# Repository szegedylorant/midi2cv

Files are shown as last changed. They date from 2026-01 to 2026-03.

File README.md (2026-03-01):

# MIDI Interface

MIDI to Clock, CV and Gate interface in 4 hp wide Eurorack format based on the Arduino Nano v3.

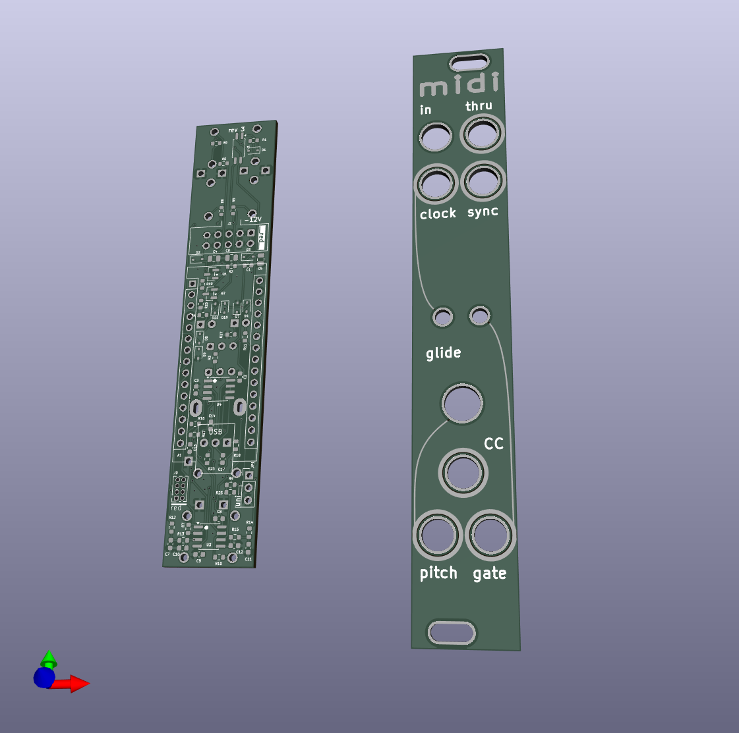
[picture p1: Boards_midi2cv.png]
Boards Image
 "3d rendered image of the two boards"

## Functions

* 4hp wide
* TRS MIDI Type A
* Hardware MIDI Thru
* MIDI clock to 16th note clock signal
* MIDI clock to DIN SYNC 24ppqn signal
* MIDI CC using 7 bit PWM Output
* 1V / Octave Pitch CV using 7 bit PWM Output
* Note glide knob
* Note on gate output

## Sources

### Code based on:
* - https://github.com/dhaillant/midi8d
* - https://github.com/kassu/KassutronicsQuantizer
 
### Hardware based on:
* - https://n-audio.net/designing-midi-in-and-midi-out-schematics/
* - https://github.com/dhaillant/midi8d
* - https://github.com/kassu/kassutronics/tree/master/documentation/Quantizer

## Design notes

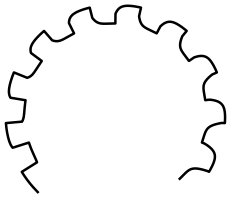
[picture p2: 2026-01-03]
hardware/square_to_lowpass_arc_270deg_CW_RCx1p5_tight.png

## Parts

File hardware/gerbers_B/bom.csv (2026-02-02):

Comment | Designator | Footprint | LCSC
4k7 | R24,R27 | Resistor_SMD:R_0603_1608Metric | C23162
1N5819WS | D2,D3,D4,D7,D8,D9,D10,D11 | Diode_SMD:D_SOD-323 | C191023
1k | R2,R7,R8,R9,R10,R11,R19,R20,R23 | Resistor_SMD:R_0603_1608Metric | C21190
10u | C4,C5,C6 | Capacitor_SMD:C_0805_2012Metric | C15850
100n | C1,C2,C3,C8,C9 | Capacitor_SMD:C_0603_1608Metric | C14663
TL072 | U3,U4 | Package_SO:SOIC-8_3.9x4.9mm_P1.27mm | C6961
10n | C17 | Capacitor_SMD:C_0603_1608Metric | C57112
15k | R12,R13,R14,R15,R16,R17 | Resistor_SMD:R_0603_1608Metric | C22809
1n | C7,C10,C11,C12,C13,C14 | Capacitor_SMD:C_0603_1608Metric | C1588
100k | R4,R25 | Resistor_SMD:R_0603_1608Metric | C25803
100 | R18 | Resistor_SMD:R_0603_1608Metric | C22775
1M | R3 | Resistor_SMD:R_0603_1608Metric | C22935
220R | R1,R5,R6 | Resistor_SMD:R_0603_1608Metric | C22962
MMBT5551L | Q1,Q2 | Package_TO_SOT_SMD:SOT-23 | C2145
1N4148WS | D1 | Diode_SMD:D_SOD-323 | C2128
EL3H7(C)(TA)-G | U1 | Package_SO:SSOP-4_4.4x2.6mm_P1.27mm | C92243

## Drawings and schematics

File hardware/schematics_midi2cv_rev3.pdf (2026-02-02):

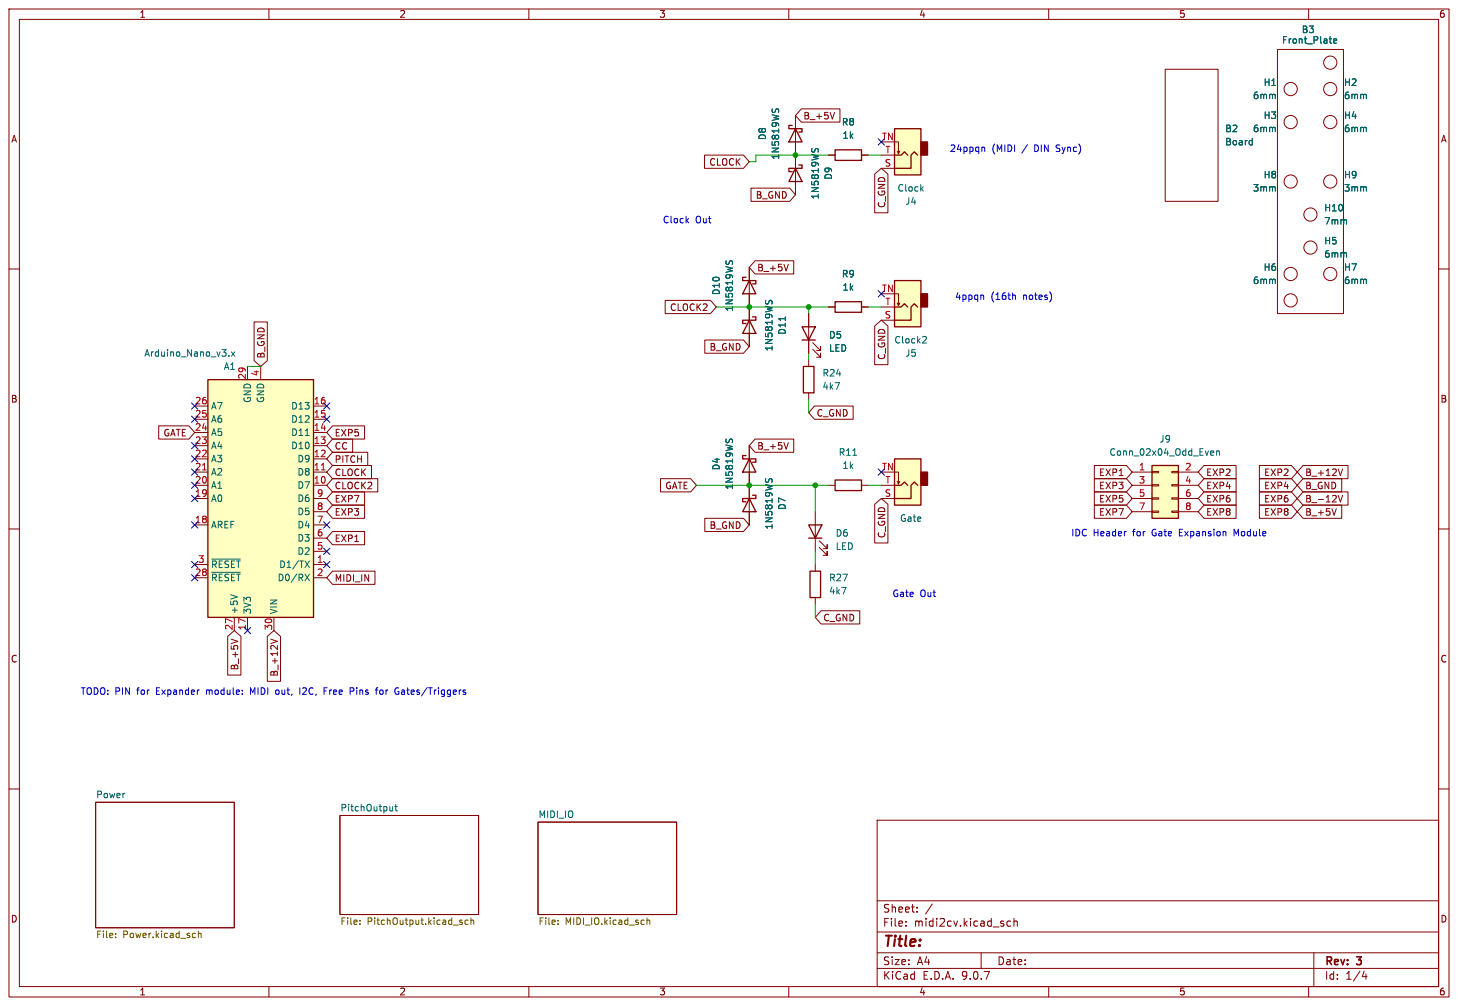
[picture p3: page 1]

Id: 1/4 Title: File: midi2cv.kicad_sch Sheet: / MIDI_IO

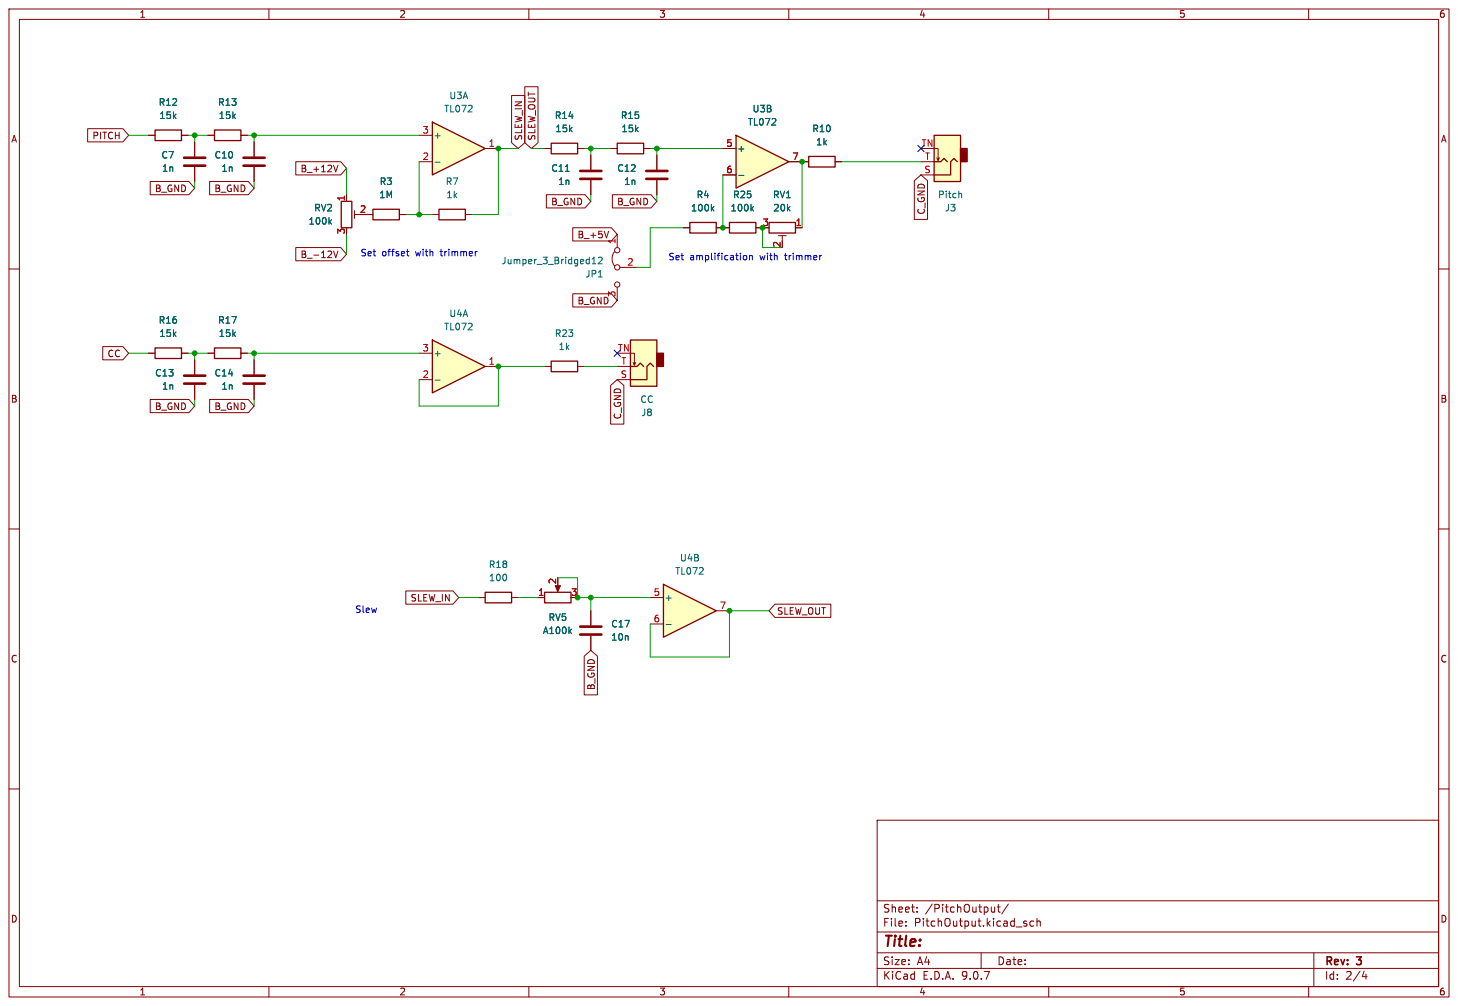
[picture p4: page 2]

Id: 2/4 Title: File: PitchOutput.kicad_sch Sheet: /PitchOutput/

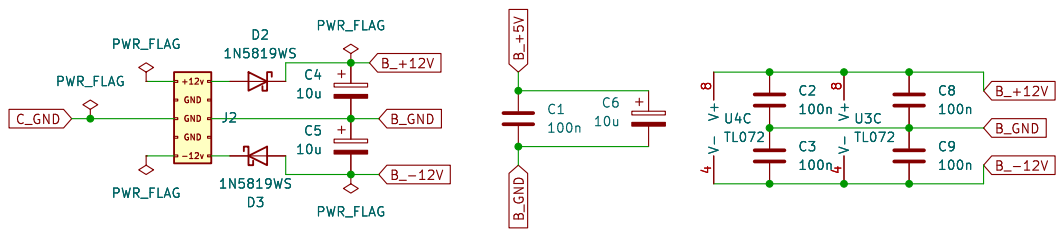
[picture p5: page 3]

Id: 3/4 Title: File: Power.kicad_sch Sheet: /Power/

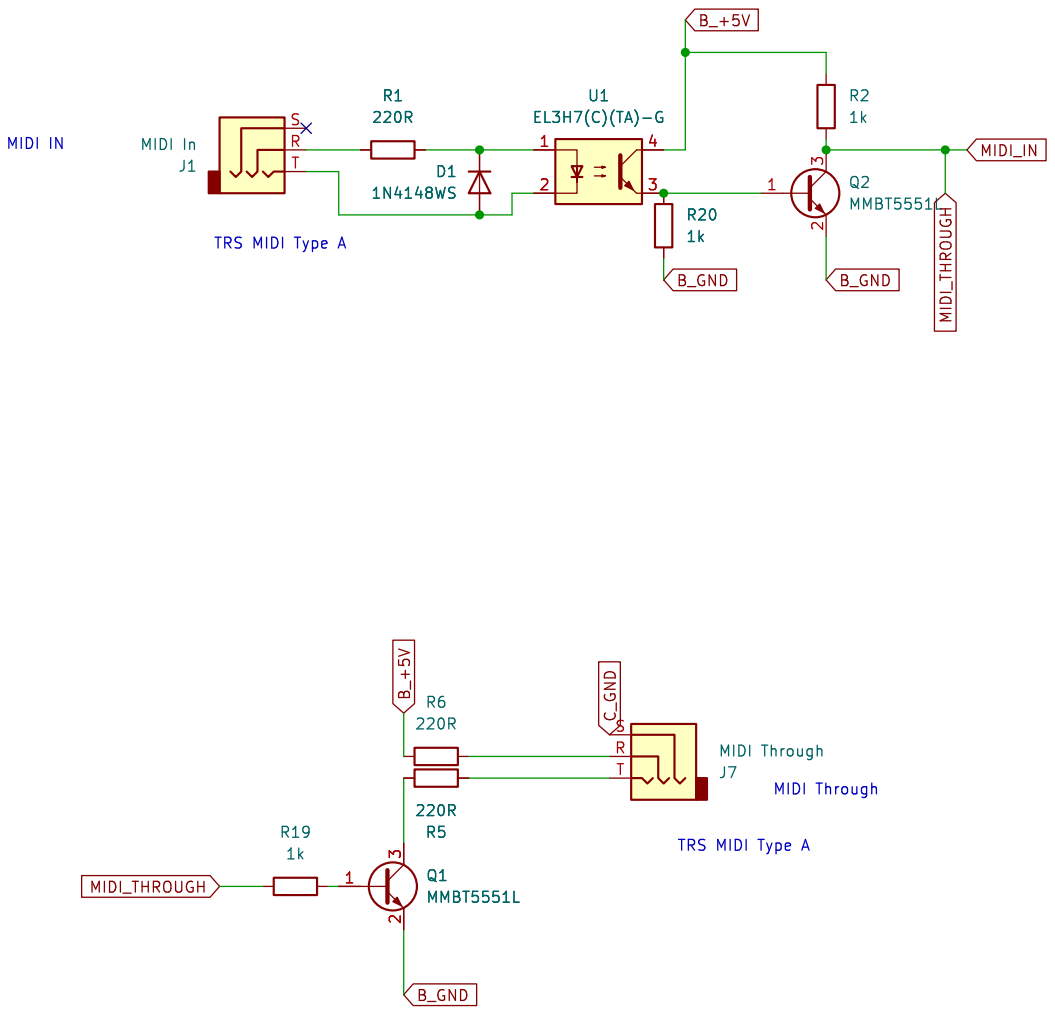
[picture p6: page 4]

TRS MIDI Type A MIDI Through Q1 MMBT5551L

Id: 4/4 Title: File: MIDI_IO.kicad_sch Sheet: /MIDI_IO/

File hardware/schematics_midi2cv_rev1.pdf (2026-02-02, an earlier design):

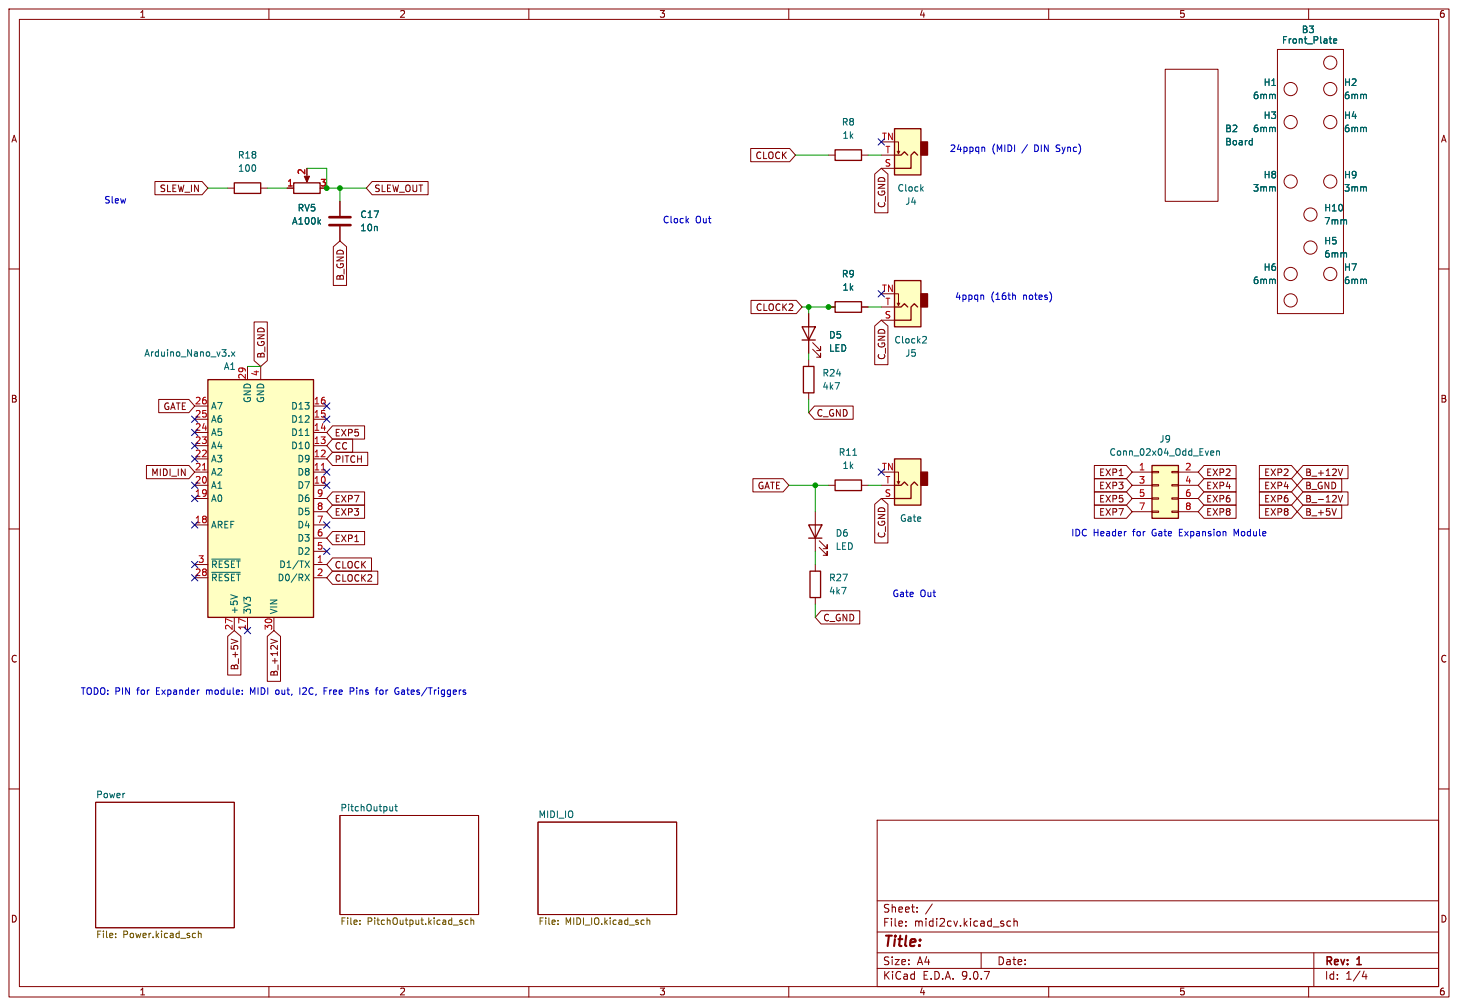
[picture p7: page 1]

24ppqn (MIDI / DIN Sync) Clock Out

IDC Header for Gate Expansion Module TODO: PIN for Expander module: MIDI out, I2C, Free Pins for Gates/Triggers

Id: 1/4 Title: File: midi2cv.kicad_sch Sheet: / MIDI_IO

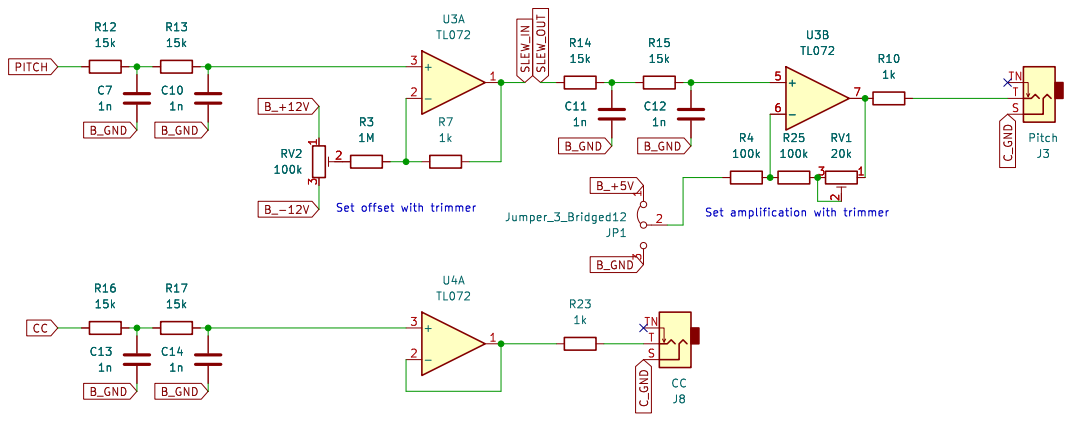
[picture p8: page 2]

Id: 2/4 Title: File: PitchOutput.kicad_sch Sheet: /PitchOutput/

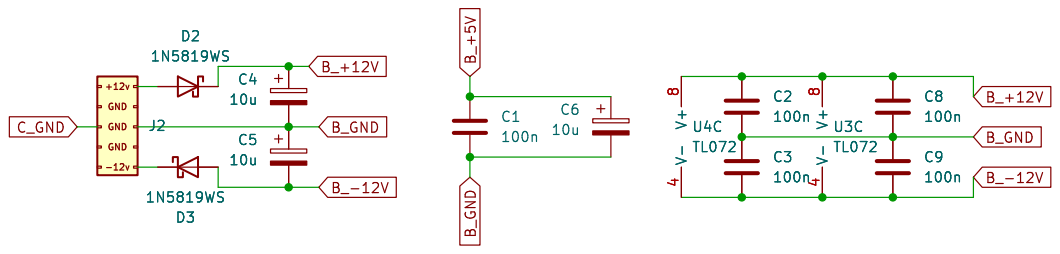
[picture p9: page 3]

Id: 3/4 Title: File: Power.kicad_sch Sheet: /Power/

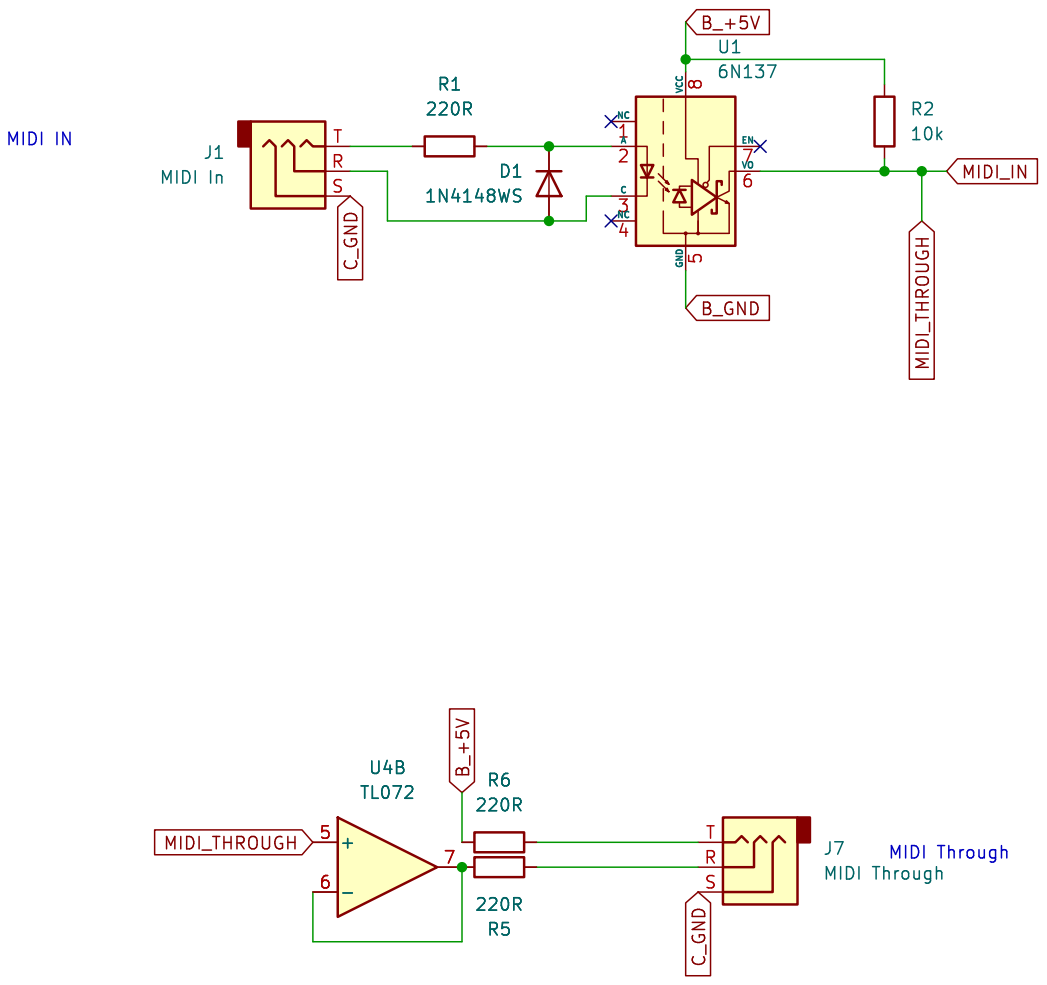
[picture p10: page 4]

Id: 4/4 Title: File: MIDI_IO.kicad_sch Sheet: /MIDI_IO/ R5

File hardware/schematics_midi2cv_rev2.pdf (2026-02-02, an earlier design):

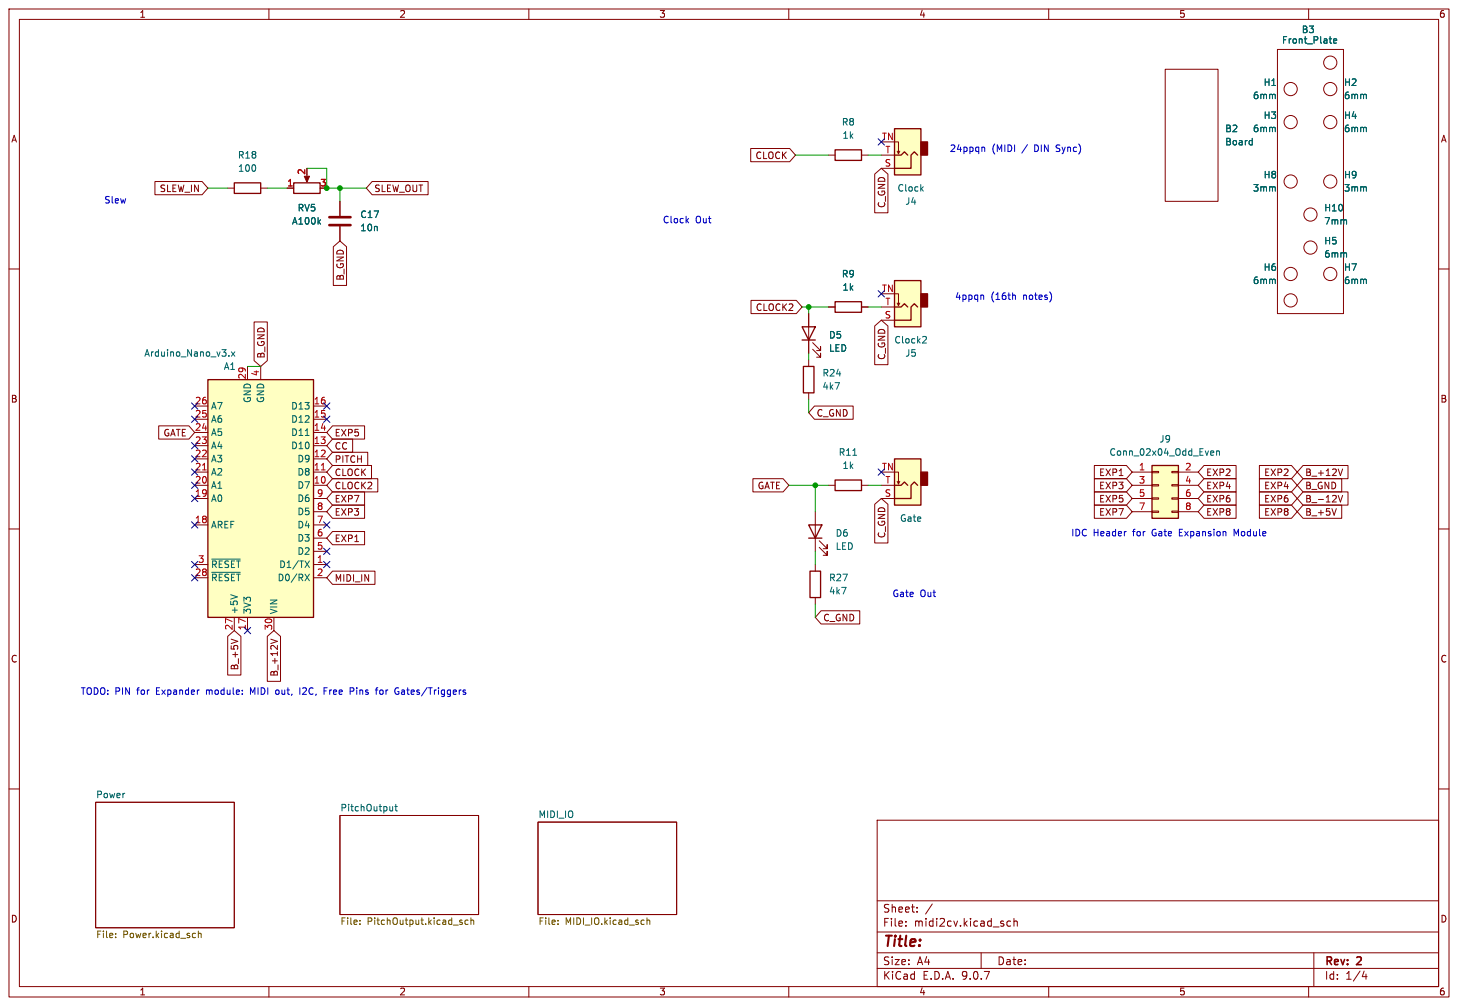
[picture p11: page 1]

24ppqn (MIDI / DIN Sync) TODO: PIN for Expander module: MIDI out, I2C, Free Pins for Gates/Triggers

IDC Header for Gate Expansion Module Gate Out R9

Id: 1/4 Title: File: midi2cv.kicad_sch Sheet: / MIDI_IO

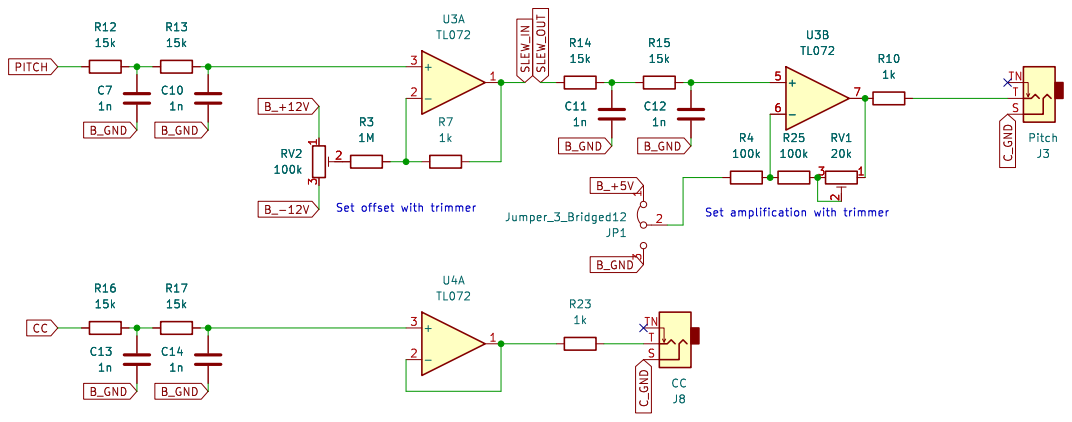
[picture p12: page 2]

Id: 2/4 Title: File: PitchOutput.kicad_sch Sheet: /PitchOutput/


Id: 3/4 Title: File: Power.kicad_sch Sheet: /Power/


Id: 4/4 Title: File: MIDI_IO.kicad_sch Sheet: /MIDI_IO/ R5

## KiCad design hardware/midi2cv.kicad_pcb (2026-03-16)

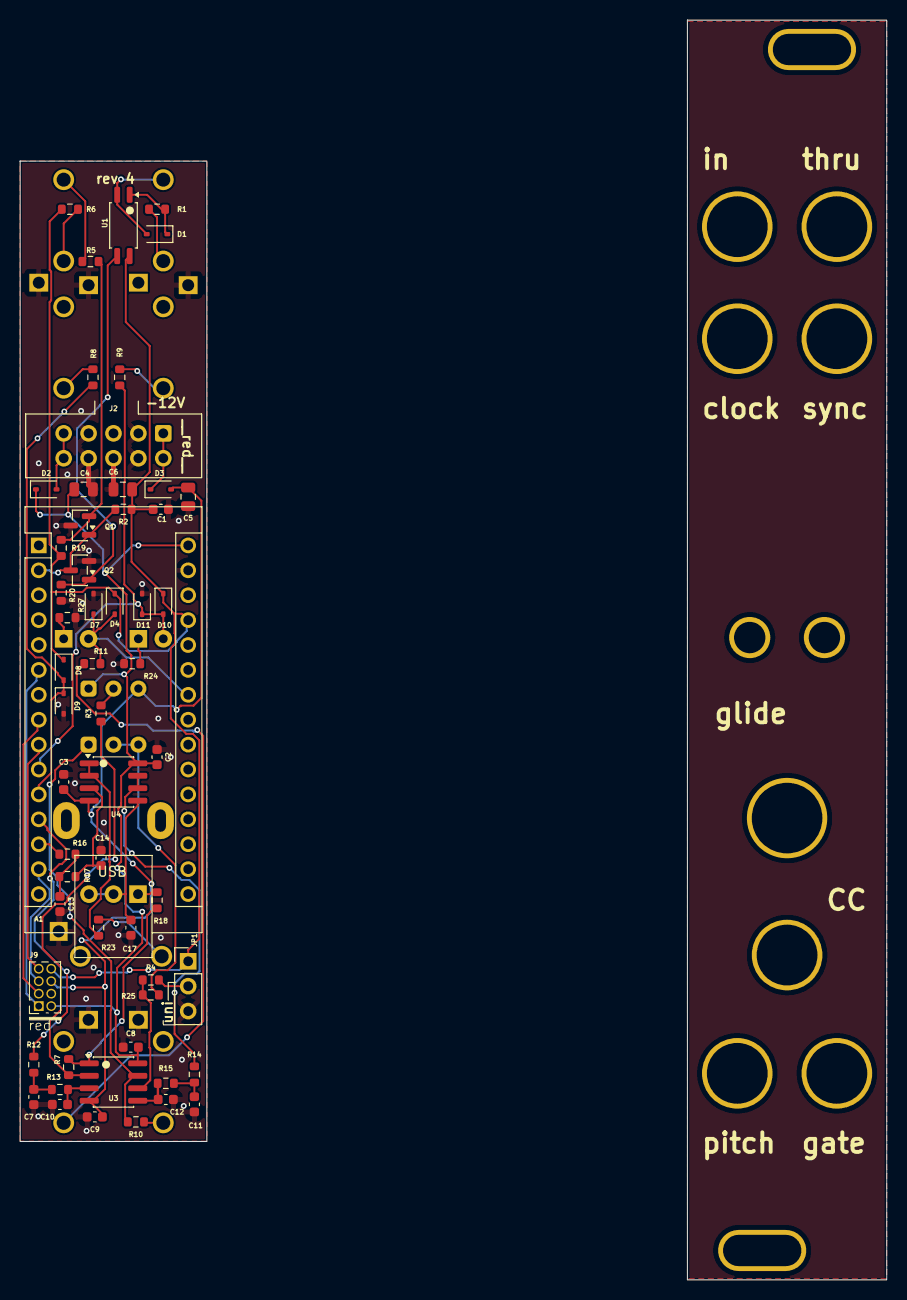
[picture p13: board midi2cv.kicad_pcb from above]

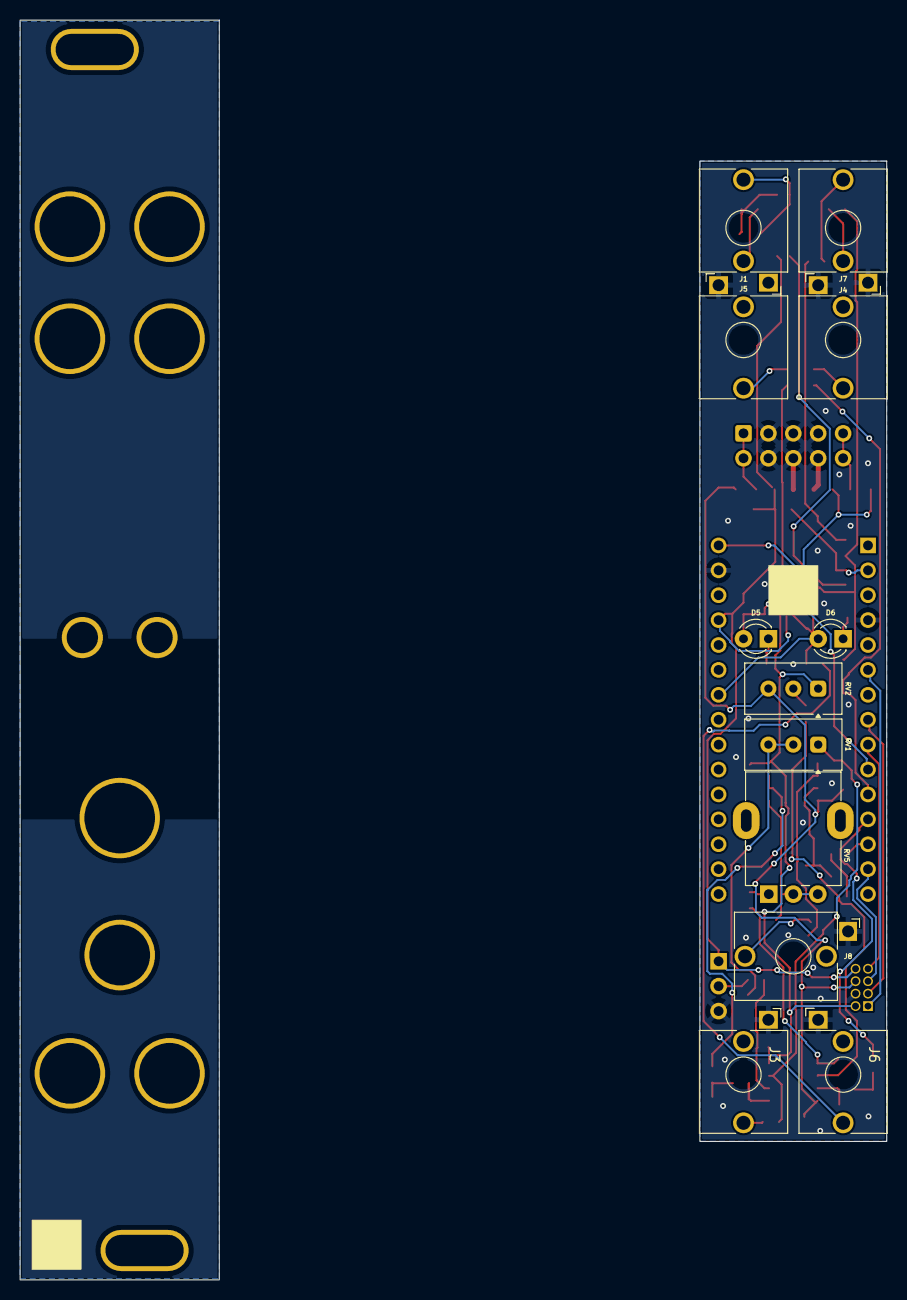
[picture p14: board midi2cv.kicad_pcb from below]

Board: 2 copper layers, 19.1 x 100.0 mm, 83 parts (12 on the bottom side), 47 nets.

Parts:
A1: Arduino_Nano_v3.x; Arduino_Nano
B: Board
B2: Board; Board_4hp_100mm
B3: Front_Plate; Front_Plate_4hp_cut
C1, C2, C3, C8, C9: 100n; C_0603_1608Metric
C4, C5, C6: 10u; C_0805_2012Metric
C7, C10, C11, C12, C13, C14: 1n; C_0603_1608Metric
C17: 470n; C_0603_1608Metric
D1: 1N4148WS; D_SOD-323
D2, D3, D4, D7, D8, D9, D10, D11: 1N5819WS; D_SOD-323
D5, D6: LED; LED_D3.0mm
F: Board
H1, H2, H3, H4, H5, H6, H7: 6mm; DrillHole_D6.00
H8, H9: 3mm; DrillHole_D3.00
H10: 7mm; DrillHole_D7.00
J1: MIDI In; Jack_3.5mm_QingPu_WQP-PJ366ST_Vertical_CircularHoles_L
J2: EuroPower10_THT; IDC-Header_2x05_P2.54mm_Vertical_PinOnly
J3: Pitch; Jack_3.5mm_QingPu_WQP-PJ398SM_Vertical_CircularHoles_R
J4: Clock; Jack_3.5mm_QingPu_WQP-PJ398SM_Vertical_CircularHoles_L
J5: Clock2; Jack_3.5mm_QingPu_WQP-PJ398SM_Vertical_CircularHoles_L
J6: Gate; Jack_3.5mm_QingPu_WQP-PJ398SM_Vertical_CircularHoles_L
J7: MIDI Through; Jack_3.5mm_QingPu_WQP-PJ366ST_Vertical_CircularHoles_L
J8: CC; Jack_3.5mm_QingPu_WQP-PJ398SM_Vertical_CircularHoles_L
J9: Conn_02x04_Odd_Even; PinSocket_2x04_P1.27mm_Vertical
JP1: Jumper_3_Bridged12; PinHeader_1x03_P2.54mm_Vertical
Q1: MMBT5401; SOT-23
Q2: MMBT5551L; SOT-23
R1, R5, R6: 220R; R_0603_1608Metric
R2, R7, R8, R9, R10, R11, R19, R20, R23: 1k; R_0603_1608Metric
R3: 1M; R_0603_1608Metric
R4, R25: 100k; R_0603_1608Metric
R12, R13, R14, R15, R16, R17: 15k; R_0603_1608Metric
R18: 100; R_0603_1608Metric
R24, R27: 4k7; R_0603_1608Metric
RV1: 20k; Potentiometer_Vishay_T93XA_Horizontal
RV2: 100k; Potentiometer_Vishay_T93XA_Horizontal
RV5: A100k; Potentiometer_Alpha_RD901F-40-00D_Single_Vertical
U1: EL3H7(C)(TA)-G; SSOP-4_4.4x2.6mm_P1.27mm
U3, U4: TL072; SOIC-8_3.9x4.9mm_P1.27mm

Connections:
+12V: D2.2 (A), J2.9 (+12V), J2.10 (+12V)
-12V: D3.1 (K), J2.1 (-12V), J2.2 (-12V)
B_+5V: A1.27 (+5V), C1.1, C6.1, D4.1 (K), D8.1 (K), D10.1 (K), J9.8, JP1.1 (A), R2.2, R6.1, R19.2, U1.4
B_+12V: A1.30 (VIN), C2.1, C4.1, C8.1, D2.1 (K), J9.2, RV2.1, U3.8 (V+), U4.8 (V+)
B_-12V: C3.2, C5.2, C9.2, D3.2 (A), J9.6, RV2.3, U3.4 (V-), U4.4 (V-)
B_GND: A1.4 (GND), A1.29 (GND), C1.2, C2.2, C3.1, C4.2, C5.1, C6.2, C7.2, C8.2, C9.1, C10.2, C11.2, C12.2, C13.2, C14.2, C17.2, D7.2 (A), D9.2 (A), D11.2 (A), J2.3 (GND), J2.4 (GND), J2.5 (GND), J2.6 (GND), J2.7 (GND), J2.8 (GND), J3.S, J4.S, J5.S, J6.S, J7.S, J8.S, J9.4, JP1.3 (B), Q1.3 (C), Q2.2 (E), R20.1, R24.2, R27.2
CC: A1.13 (D10), R16.2
CLOCK: A1.11 (D8), D8.2 (A), D9.1 (K), R8.2
CLOCK2: A1.10 (D7), D5.2 (A), D10.2 (A), D11.1 (K), R9.2
EXP1: A1.6 (D3), J9.1
EXP3: A1.8 (D5), J9.3
EXP5: A1.14 (D11), J9.5
EXP7: A1.9 (D6), J9.7
GATE: A1.24 (A5), D4.2 (A), D6.2 (A), D7.1 (K), R11.2
MIDI_IN: A1.2 (D0/RX), Q1.1 (B), Q2.3 (C), R2.1
unnamed: C7.1, R12.1, R13.2
unnamed: C11.1, R14.1, R15.2
unnamed: C13.1, R16.1, R17.2
unnamed: D1.2 (A), J1.T, U1.2
unnamed: D1.1 (K), R1.2, U1.1
unnamed: D5.1 (K), R24.1
unnamed: D6.1 (K), R27.1
unnamed: J1.R, R1.1
unnamed: J3.T, R10.1
unnamed: J4.T, R8.1
unnamed: J5.T, R9.1
unnamed: J6.T, R11.1
unnamed: J7.R, R6.2
unnamed: J7.T, R5.2
unnamed: J8.T, R23.1
unnamed: JP1.2 (C), R4.2
unnamed: Q1.2 (E), R5.1, R19.1
unnamed: Q2.1 (B), R20.2, U1.3
unnamed: R3.2, RV2.2
unnamed: R10.2, RV1.1, U3.7
unnamed: R18.1, RV5.1
unnamed: R25.1, RV1.2, RV1.3
unnamed: C10.1, R13.1, U3.3 (+)
unnamed: R3.1, R7.2, U3.2 (-)
unnamed: C12.1, R15.1, U3.5 (+)
unnamed: R4.1, R25.2, U3.6 (-)
unnamed: C14.1, R17.1, U4.3 (+)
unnamed: R23.2, U4.1, U4.2 (-)
unnamed: C17.1, RV5.2, RV5.3, U4.5 (+)
PITCH: A1.12 (D9), R12.2
SLEW_IN: R7.1, R18.2, U3.1
SLEW_OUT: R14.2, U4.6 (-), U4.7

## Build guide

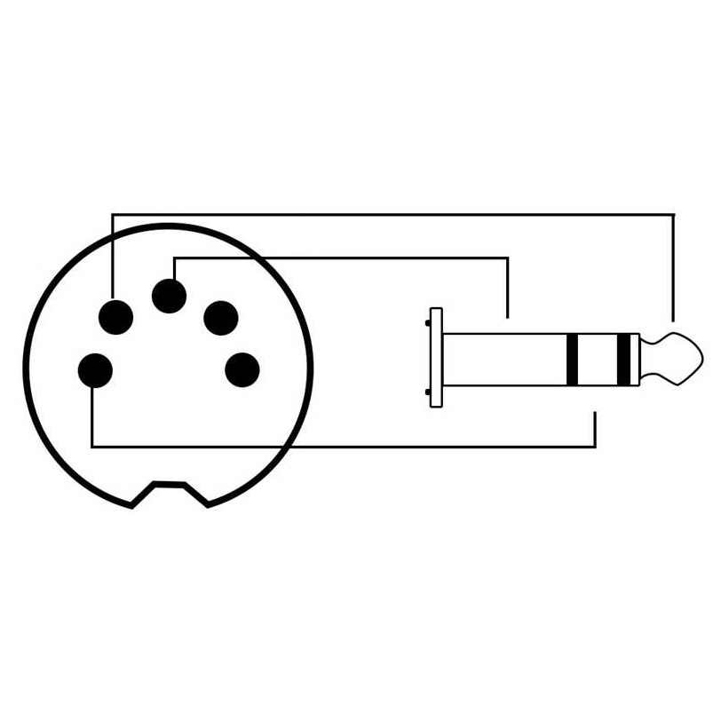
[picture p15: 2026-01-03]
hardware/5963-5-pin-din-plug-wiring-diagram.jpg

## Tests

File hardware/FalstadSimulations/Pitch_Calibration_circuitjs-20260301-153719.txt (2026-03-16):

$ 1 0.000005 10.20027730826997 50 5 50 5e-11
a 240 192 368 192 9 15 -15 1000000 1.4895850803408213 1.4895999999999998 100000
R 112 208 112 144 0 0 40 12 0 0 0.5
R 112 304 112 368 0 0 40 -12 0 0 0.5
174 112 208 112 304 1 100000 0.5396000000000001 Resistance
r 128 256 240 256 0 1000000
r 240 256 368 256 0 1000
w 240 208 240 256 0
w 368 192 368 256 0
w 368 192 448 192 2
a 448 208 560 208 9 15 -15 1000000 1.4919338191794331 1.491965917837166 100000
R 448 320 448 384 0 0 40 0 0 0 0.5
r 448 320 448 272 0 100000
r 448 272 544 272 0 100000
174 544 272 624 304 1 20000 0.7574000000000001 Resistance
w 448 224 448 272 0
w 560 208 640 208 0
w 640 208 640 272 0
w 640 208 768 208 2
w 592 304 640 304 0
w 640 304 640 272 0
R 240 176 240 96 0 2 40 0.9375 2.4271 0 0.5
p 768 208 768 304 3 0 0 10000000
g 768 304 768 336 0 0
o 20 64 0 4103 5 0.00009765625 0 2 20 3
o 17 64 0 4103 10 0.00009765625 0 2 17 3

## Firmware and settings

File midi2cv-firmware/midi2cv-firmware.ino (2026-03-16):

/*
 * MIDI Interface
 *
 * MIDI clock to 16th note clock signal
 * MIDI clock to DYN SYNC 24ppqn signal
 *
 * Code based on:
 * - https://github.com/dhaillant/midi8d
 * - https://github.com/kassu/KassutronicsQuantizer
 *
 * Hardware based on:
 * - https://n-audio.net/designing-midi-in-and-midi-out-schematics/
 * - https://electricdruid.net/product/midi-inoutthru-pcb/
 * - https://github.com/dhaillant/midi8d
 * - https://github.com/kassu/kassutronics/tree/master/documentation/Quantizer
 * 
*/
// #define PITCH_CALIBRATION 5000  // uncomment for calibration mode

// Macros to set and clear a single bit in any register
#ifndef cbi
#define cbi(sfr, bit) (_SFR_BYTE(sfr) &= ~_BV(bit))
#endif
#ifndef sbi
#define sbi(sfr, bit) (_SFR_BYTE(sfr) |= _BV(bit))
#endif

#define TRIGGER_LENGTH 1000  // clock and sync gate length in microseconds

#include <Arduino.h>
#include <MIDI.h>  // https://github.com/FortySevenEffects/arduino_midi_library.git

const uint8_t PIN_CLOCK = 8;
const uint8_t PIN_CLOCK2 = 7;

const uint8_t PIN_CC = 10;    // PWM pin
const uint8_t PIN_PITCH = 9;  // PWM pin
const uint8_t PIN_GATE = A5;

const uint8_t PIN_SERIAL_RX = 0;
const uint8_t PIN_SERIAL_TX = 1;


// currently unused pins for extension board
const uint8_t PIN_EXP1 = 3;
const uint8_t PIN_EXP3 = 5;
const uint8_t PIN_EXP5 = 11;
const uint8_t PIN_EXP7 = 6;

const uint8_t MIDI_CHANNEL = MIDI_CHANNEL_OMNI;  // Set midi channel here
const uint8_t CC_NUMBER = 27;                    // TODO: find a good default...


MIDI_CREATE_DEFAULT_INSTANCE();

bool isRunning = false;

class Trigger {
public:
  uint8_t step = 0;
  bool isTriggered = false;

  Trigger(const uint8_t pin)
    : PIN(pin) {}

  void update() {
    long now = micros();
    if (isTriggered) {  // pick up trigger signal
      triggerStart = now;
      isTriggered = false;
    }
    if (now - triggerStart < TRIGGER_LENGTH) {  // keep pin high for the predefined duration
      digitalWrite(PIN, HIGH);
    } else {
      digitalWrite(PIN, LOW);
    }
  }
private:
  const uint8_t PIN;
  long triggerStart = 0;
};

Trigger clock(PIN_CLOCK2);
Trigger sync(PIN_CLOCK);

void startupBlinkLED() {
  digitalWrite(PIN_GATE, LOW);
  digitalWrite(PIN_CLOCK2, LOW);
  delay(1000);
  digitalWrite(PIN_GATE, HIGH);
  delay(200);
  digitalWrite(PIN_GATE, LOW);
  digitalWrite(PIN_CLOCK2, HIGH);
  delay(200);
  digitalWrite(PIN_CLOCK2, LOW);
}
void setup() {
  // Serial.begin(115200);
  // Serial.begin(31250);

  setupPWM();

  pinMode(PIN_GATE, OUTPUT);
  pinMode(PIN_CLOCK, OUTPUT);
  pinMode(PIN_CLOCK2, OUTPUT);
  digitalWrite(PIN_GATE, HIGH);
  digitalWrite(PIN_CLOCK, HIGH);
  digitalWrite(PIN_CLOCK2, HIGH);

#ifndef PITCH_CALIBRATION
  MIDI.setHandleClock(handleClock);        // called on each clock pulse
  MIDI.setHandleStart(handleStart);        // called on START message
  MIDI.setHandleContinue(handleContinue);  // called on CONTINUE message
  MIDI.setHandleStop(handleStop);          // called on STOP message
  MIDI.setHandleNoteOn(handleNoteOn);
  MIDI.setHandleNoteOff(handleNoteOff);
  MIDI.setHandleControlChange(handleCC);

  MIDI.begin(MIDI_CHANNEL);  // filter MIDI channel
#endif

  delay(1000);
  // Serial.println("Serial ready...");
  startupBlinkLED();
}

void loop() {

#if defined(PITCH_CALIBRATION)
  writePitch(12);  // for unipolar output: 1V
  delay(PITCH_CALIBRATION);
  writePitch(60);  // for unipolar output: 5V
  delay(PITCH_CALIBRATION);
  writePitch(108);  // for unipolar output: 9V
  delay(PITCH_CALIBRATION);
#else
  MIDI.read();
  clock.update();
  sync.update();
#endif
}

void handleStart() {
  // Serial.println("Start");

  isRunning = true;
  sync.step = 0;
  clock.step = 0;
}

void handleContinue() {
  // Serial.println("Continue");

  isRunning = true;
}

void handleStop() {
  // Serial.println("Stop");

  isRunning = false;
}

void handleClock() {
  // Serial.println("Tick");
  if (isRunning) {
    clock.isTriggered = (clock.step == 0);
    sync.isTriggered = true;

    sync.step++;
    sync.step = sync.step % 96;  // 24ppqn MIDI clock, directly suitable for DIN SYNC; fold at each bar to avoid overflow
    clock.step = sync.step % 6;  // 16th notes; as a division of the midi clock
  }
}

void handleNoteOn(midi::Channel channel, byte note, byte velocity) {
  // convert note V/Oct
  // one step in the PWM output is one note, so only shift could be adjusted
  // Pitch output needs hardware calibration
  // C-2 is midi note 0
  // C 3 is midi note 60
  // C 8 is midi note 120
  uint8_t noteIndex = note;
  writePitch(noteIndex);

  // gate on unless velocity is 0
  if (velocity == 0) {
    digitalWrite(PIN_GATE, LOW);
  } else {
    digitalWrite(PIN_GATE, HIGH);
  }
}

void handleNoteOff(midi::Channel channel, byte note, byte velocity) {
  // keep last pitch aka do nothing
  // gate off
  digitalWrite(PIN_GATE, LOW);
}

void handleCC(midi::Channel channel, byte cc_number, byte value) {
  if (cc_number == CC_NUMBER) {  // filter CC number
    writeCC(value);
  }
}

// This is taken from https://github.com/kassu/KassutronicsQuantizer/blob/master/KassutronicsQuantizer/Hardware.ino
void setupPWM() {
  // Setup timer1 for PWM on pin 9 and 10

  // The pins should be outputs
  pinMode(PIN_PITCH, OUTPUT);
  // pinMode(9, OUTPUT);
  pinMode(PIN_CC, OUTPUT);
  // pinMode(10, OUTPUT);

  // --- Clock prescaler ---
  // The PWM clock runs at the CPU rate (16 MHz) divided by a prescaler.
  // For settings 0x01 -- 0x05, the prescaler is 1, 8, 64, 256, 1024, respectively.
  // We use the fastest option:
  TCCR1B = TCCR1B & 0b11111000 | 0x01;

  // --- Waveform Generation Mode (WGM)
  /* WGM13:0 sets the PWM mode. Of the 16 modes, these are most interesting:
     5 - 7: Fast PWM 8-10 bit, respectively
     14: Fast PWM, frequency set by ICR1 register
     15: Fast PWM, frequency set by OCR1A register
 
     In mode 14 and 15, the PWM frequency can be chosen very flexibly: 
  
         fPWM = fCPU / (N * (TOP+1))
  
     where fIO is the CPU clock, N is the prescaler set above and TOP is the value in
     either ICR1 or OCR1A (mode 14 or 15, resp.).
     
     We use mode 14, because then we can freely choose the frequency, but have the OCR1A register
     available to control the PWM on pin 9.
    */
  // The mode setting is spread over the two timer registers,so we set it one bit at the time (14 = 0b1110 = set set set clear)
  sbi(TCCR1B, WGM13);
  sbi(TCCR1B, WGM12);
  sbi(TCCR1A, WGM11);
  cbi(TCCR1A, WGM10);

  // Set ICR1 register define frequency (see formula above) and resolution (valid output values are 0 to ICR1)
  //ICR1 = 0x01FF; // 9 bit
  ICR1 = 0x007F;  // 7 bit

  // Compare Output Mode - COM1A1, COM1A0, COM1B1, COM1B0 (first 4 bits of TCCR1A, respectively)
  // These set the mode for output A (=pin 9) and output B (=pin 10), respectively. In fast PWM mode, the modes are:
  //   0b00 - Normal port (disable PWM)
  //   0b01 - Only in WGM mode 14 or 15 (see above): Toggle output A on Compare Match. Output B is normal port (PWM disabled)
  //          I'm not sure what the point of this is. It seems you get always 50% duty cycle and half the normal fast PWM frequency,
  //          but then you can set the phase with register OCR1A (or analogWrite(9,phase) )
  //   0b10 - non-inverting PWM
  //   0b11 - inverting PWM
  // Arduinos analogWrite sets the first bit for the respective port each time you call analogWrite (so you can switch to
  // digitalWrite and back whenever you feel like it). Let's set them all explicitly in the beginning, so we can write the
  // registers directly.
  sbi(TCCR1A, COM1A1);
  cbi(TCCR1A, COM1A0);
  sbi(TCCR1A, COM1B1);
  cbi(TCCR1A, COM1B0);

  // Write 0 to both ports as initial value
  OCR1A = 0;
  OCR1B = 0;
}

inline void writePitch(uint8_t pitch) {
  OCR1A = pitch - 1; // TODO: fix offset adjustment range in hardware
}

inline void writeCC(uint8_t cc) {
  OCR1B = cc;
}

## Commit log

2025-11-20 first schematics sketch
    [midi2cv.kicad_pcb, midi2cv.kicad_sch]
2025-11-20 add stereo jack footprint
2026-01-03 routed pcb
    [MIDI_IO.kicad_sch, PitchOutput.kicad_sch, Power.kicad_sch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]
2026-01-03 update routing
    [midi2cv.kicad_pcb]
2026-01-04 add gerbers and bom
    [MIDI_IO.kicad_sch, PitchOutput.kicad_sch, Power.kicad_sch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]
2026-02-02 add rev 2 and rev 3, now with correct trs midi A
    [MIDI_IO.kicad_sch, PitchOutput.kicad_sch, Power.kicad_sch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]
2026-02-02 update firmware with calibration
2026-02-05 reorganize folders
    [MIDI_IO.kicad_sch, PitchOutput.kicad_sch, Power.kicad_sch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]
2026-03-01 main board rev 4: fix midi thru, led arrangement, glide cap value. fix sync trigger output
    [MIDI_IO.kicad_sch, PitchOutput.kicad_sch, Power.kicad_sch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]
2026-03-16 update calibration
    [midi2cv.kicad_pcb]
